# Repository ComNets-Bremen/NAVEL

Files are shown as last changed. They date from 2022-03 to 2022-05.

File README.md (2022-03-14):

# NAVEL - Logistics Innovation Center

Any country requires home grown solutions to solve problems faced by different stake holders of the society of those countries. One such area is in finding solutions to problems in ensuring the safety of food during transporting. The ideas and easy-to-use technology that is associated with the Internet of Things (IoT) enable developing cost-effective solutions to many such problems. NAVEL is the name given to a project funded by the German Aerospace Center (DLR) to build a Logistics Innovation Center in Cameroon. The aim of the project is to build a "Fab Lab" with computing hardware and the know-how, available to entrepreneurs to try out new ideas and tehnological solutions required in their businesses.

To demonstrate the possibilities of the Fab Lab, we have built simple IoT solutions for some selected use cases and the related problems. This repostory provides the details of these solutions in terms of the protypes developed and the training material required to build such protoypes.

We hope that this will inspire the users of the Fab Lab to find solutions to their problems.

The different sections of this repository is organized in the following manner.

- [Training Material](./training-material) - This sections provides a number of HOWTOs on using the technologies of the IoT to find solutions to problems.
- [Prototypes](./prototypes) - This section provides details of the different protoypes developed to show the possibilities of the Fab Lab.

Click on the link to browse the content of the section.

For inquiries about the material in this repository or comments, contacts us using navel@comnets.uni-bremen.de

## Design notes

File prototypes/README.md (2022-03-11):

# NAVEL - Prototypes

To demonstrate the possibilities of the FAB Lab, a prototypes are developed addressing specific yuse cases. The items listed below and their corresponding links provide details of each prototype developed.

- [Food Safety Prototype](./Food-Safety-Prototype)

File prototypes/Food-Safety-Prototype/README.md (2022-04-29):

# Food Safety Prototype

The Food Safety Prototype demonstrates how the resources available at the FAB Lab can be used to develop a solution for a specific use case. The use case relates to transporting meat or milk safely in Cameroon. This README provides the details of the scenario, the hardware used and the code of the prototype. The following locations have further details.

- [Design](./design/) - Contains the flow charts of the prograsm logic, pin assignments, etc.
- [Program code](./code/) - Contains the program code of the prototype

## Scenario

There are a number of different transportation means used by producers of meat and milk to deliver them to the sellers who will further process or sell directly to customers. During the transportation, the products are refrigerated but due to technical reasons, the refrigeration may fail. But, to know whether such a failure occured, there is not control mechanisms adopted.

The idea of this prototype is to build a self contained temperature monitoring device that is able to inform the sellers about the changes of the temperature during transport. The prototype will consit of a visual indicator to indicate whether temperature had exceeded a certain threshold during the transportation. Addition to this indications, the prototype also logs the temperature with time. For further analysis, the sellers can download this information to analyse the behaviour.

The picture below shows the protoype. It consist of the following components.

- Temperature sensor
- Button
- 3 LEDs (Red, Green and Yellow)

<p align="center">
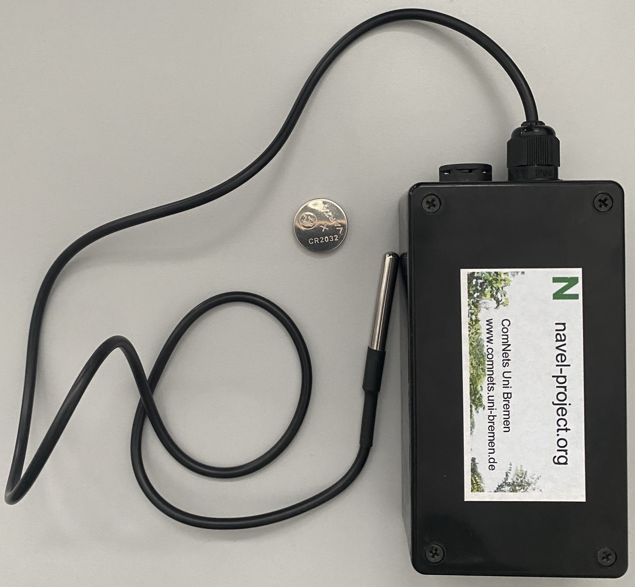
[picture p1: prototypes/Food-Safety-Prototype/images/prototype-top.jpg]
Prototype from top
    
</p>
<p align="center">
    <em>The protype from the top with its temperature sensor against the backdrop of a CR2032 coin battery</em>
</p>

<p align="center">
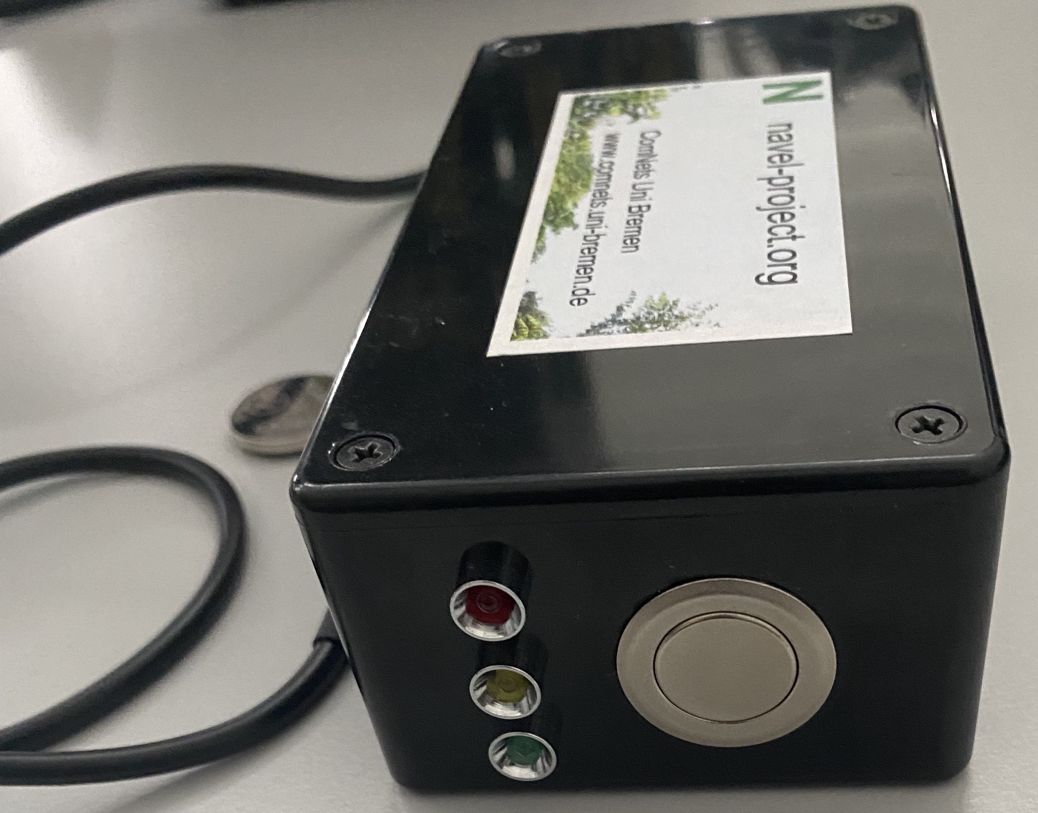
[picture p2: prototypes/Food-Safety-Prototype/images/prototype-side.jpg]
Prototype from side
    
</p>
<p align="center">
    <em>The protype from the side where the button and the 3 LEDs are visible</em>
</p>

The operation of the prototype is described in the following text.

- When the prototype boots up, the red and green LEDs will blink sequentially 3 times to indicate that it is ready for operation.
- When the button is pressed for a short time, between 3 and 7 seconds, the prototype will start logging the temperature. 
- The temperature will be logged every 10 seconds together with a green blink of the LED.
- When logging the temperature, if the average temperature from the last 8 readings exceeds a threshold (set to 7 degrees celcius), then the red LED will be lit permenently until a reset is done.
- If a long button press is performed, a press above 8 seconds, the a WLAN access point and a web server is brout up by the protype.
- The user can connect to this WLAN AP and use a web browser to browse and download data.
- A the same short press above, if done while the temperature is being logged, results in clearing the threshold exceed indicator (red LED) and starting a new round of temperature logging.

## Hardware

The prototype is based on the `Wemos D1 ESP8266` board placed together with other shields. The list of shields used are as follows.

- Wemos D1 ESP8266 shield
- SD card shield
- Battery shield
- Port explansion shield

The components attached to these sheilds are as follows.

- 3 LEDs (red green and yellow)
- DS18S20 temperature sensor connected over 1-wire interface
- Push button
- 3.7V 2600mAh rechargeable battery
- Cables connecting the pins and the components

The picture below shows the prototype opened up.

<p align="center">
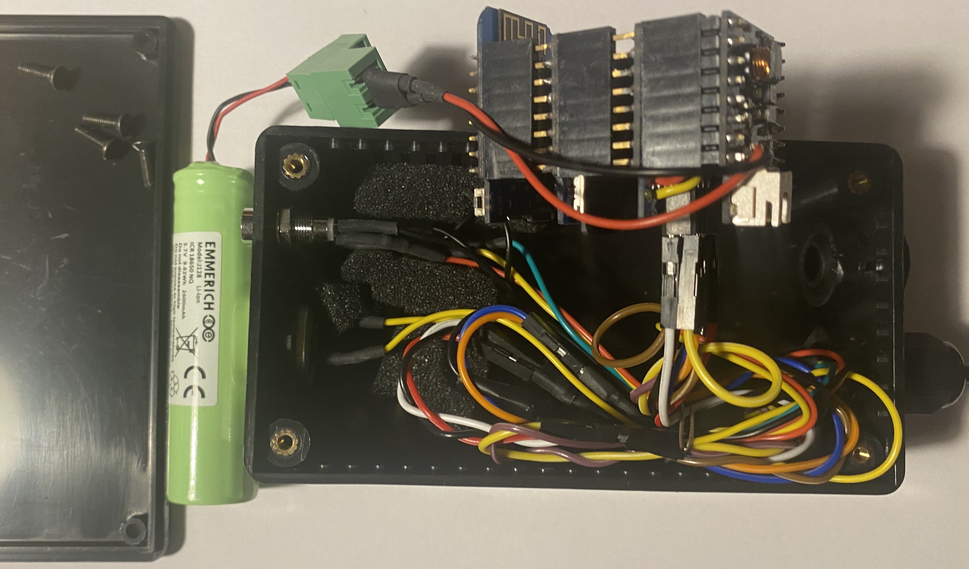
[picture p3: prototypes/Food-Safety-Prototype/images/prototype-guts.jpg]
Prototype guts
    
</p>
<p align="center">
    <em>The prototype open showing all components and connections</em>
</p>

The following table lists the pin assignments of the prototype.

| Pin on Board | Pin on ESP8266  | Details |
|---|---|---|
| TX | TXD | TXD (don't use) |
| RX | RXD | RXD (don't use) |
| A0 | A0 | Analog input, max 3.2V, not used |
| D0 | GPIO16 | Connected to RST |
| D1 | GPIO5 | Green LED |
| D2 | GPIO4 | Red LED |
| D3 | GPIO0 | Button -> GND (Pullup) |
| D4 | GPIO2 | IO, 10k Pull-up built-in LED, OneWire sensor Data  |
| D5 | GPIO14 | CLK SDcard |
| D6 | GPIO12 | MISO SDcard |
| D7 | GPIO13 | MOSI SDcard |
| D8 | GPIO15 | SS SDcard |
| G | GND | Ground |
| 5V | 5V | not available |
| 3V3 | 3.3V | 3.3V connection |
| RST | RST | Reset |

## Code

The code of the program consist of a number of parts (listed below) that are invoked to perform different activities. 

- Reading temperature sensor
- Averaging temperature values to check whether threshold exceeded
- Handling button presses (long press or short press) through an interrupt handler
- Setting up temperature logging
- Starting or stopping the WLAN access point and the web server
- Writing to SD card
- Setting up web server with the logged data
- Sleeping to save energy
- Serving web pages
- Forcing memory usage cleanup (garbage collection)

The following sections show and describe the code related to the above activities.

#### Reading temperature sensor

The sensor is connected over a [1-Wire](https://en.wikipedia.org/wiki/1-Wire) interface. This interface may be used by multiple sensors and therefore, it has to be initialized and a handle must be obtained for the temperature sensor to work with.

```Python
# Enable one wire temerature sensor
ow = onewire.OneWire(machine.Pin(2))
ow.scan()                # return a list of devices on the bus
ow.reset()               # reset the bus
ds = ds18x20.DS18X20(ow) # get handle
```

With the obtained handle, the function below retrives the value (i.e., the temperature) reported by the sensor.

```Python
# read temperature value from sensor
def read_sensors():
    temp = 0
    roms = ds.scan()
    ds.convert_temp()
    time.sleep_ms(750)
    res = {}
    for rom in roms:
        temp = ds.read_temp(rom)
        res[ubinascii.hexlify(rom)] = temp
    res["time"] = str(time.time())
    return res, temp
```
This part of the program code shows the actual call to the function to get the temperature and store it in a dictionary, so that it can be written to the log in the JSON format. 

```Python
# read temperature from sensor
data = {}
data["id"] = esp.flash_id()
data["data"], temp = read_sensors()
```

#### Averaging temperature and checking threshold

An array is maintained to collect the last 8 readings. These values are averaged  to check whether a threshold temperature value is exceeded. If exceeded, then the red LED must be lit until the next reset.

```Python

# add to list
average_list.append(temp)

# perform threshold check
if len(average_list) >= TEMP_AVG_FREQ:

    # compute average
    average = sum(average_list)/len(average_list)

    # init list
    average_list = []

    # check threshold to light red LED and log
    if average >= TEMP_EXCEED_LIMIT:
        led_red.value(1)
        data['msg'] = ('Threshold of ' + str(TEMP_EXCEED_LIMIT) + ' degrees was crossed')
```

#### Handling button presses

Button presses are handled using an interrupt handler. First the interrupt handler must be set.

```Python
# setup button handler (call function)
button.irq(handler=interrupt_handler, trigger=machine.Pin.IRQ_FALLING)
```

Once the interrupt handler is invoked, the button press duration must be calculated. A delay and a counter is used to figure out how long the button was pressed.

```Python
def interrupt_handler(x):
    global session, new_fileid

    # count button press duration
    x = 0
    while button.value() == 0:
        time.sleep(1)
        x += 1
```

#### Setup for temperature logging

If the press is short (between 3 and 7 seconds), then the green LED is blinked and temperature logging is initialized by creating a new log file.

```Python
# check if short press, then log temperature
if x >= 3 and x <= 7:

    # start temperature logging
    logstarted = True

    # init LEDs
    led_green.value(0)
    led_red.value(0)

    # blink green
    for i in range(6):
        led_green.value(not led_green.value())
        time.sleep(SLOW_BLINK_DURATION_SEC)

    # create new log file and log first temperature
    last_fileid += 1
    filename = '/sd/' + DATA_FILENAME + str(last_fileid)
    data = {}
    data['id'] = esp.flash_id()
    data['data'], temp = read_sensors()
    store_data(filename, data)
```

#### Setting up or brining down web server

If the press is long (beyond 8), then the red LED is blinked and actions related to brining up or taking down the WLAN access point and the we server are taken. This is indicated by the state variable `webstarted`.

The long press checking code is as follows.

```Python
# check if long press, then start web server
if x >= 8:

    # blink red
    for i in range(6):
        led_red.value(not led_red.value())
        time.sleep(SLOW_BLINK_DURATION_SEC)
    led_red.value(0)

    ...
```

Once the long presee is detected, then using the `webstarted` actions for starting or stopping web server is done. If the access point and web server are not up, the code below shows how it is brought up. 

```Python
 # start or stop WLAN AP and web server
 if not webstarted:

     # say web server and AP is active now
     webstarted = True

     # bring up WLAN AP
     ap = network.WLAN(network.AP_IF)
     ap.active(True)
     ap.config(password='navel2021')
     while ap.active() == False:
         pass

     # set up web server om port 80
     ssocket = socket.socket(socket.AF_INET, socket.SOCK_STREAM)
     saddr = socket.getaddrinfo('0.0.0.0', 80)[0][-1]
     ssocket.setsockopt(socket.SOL_SOCKET, socket.SO_REUSEADDR, 1) 
     ssocket.bind(saddr)
     ssocket.listen(5)
     ssocket.setblocking(False)

     # setup polling based connections
     poll = select.poll()
     poll.register(ssocket, select.POLLIN)
     time.sleep(2)
```
There are 3 distinct actions to bringing up the web server.

- start WLAN access point with default SSID and a password
- setup server socket to listen and bind to the port 80
- setup polling to detect incomming connections

If the web server is up when the long button press is done, then action is taken to bring down the access point and web server.

```Python
...

else:
    # say web server and AP is not active any more
    webstarted = False
    if DEBUG:
        print('stopping web server')

    # unregister polling
    poll.unregister(ssocket)

    # close socket
    ssocket.close()

    # shutdown WLAN AP
    ap = network.WLAN(network.AP_IF)
    ap.active(False)
```

In this code, the previously described distinct actions are undone in reverse order.

#### Writing to SD card

To use the DS card, a handle must be obtained and then it must be mounted as a file system.

```Python
# get handle to SD card for writing and mount as volume
sd = lib.sdcard.SDCard(machine.SPI(1), machine.Pin(15))
os.mount(sd, '/sd')

# log temperature value
def store_data(filename, data):
    with open(filename, "a") as outfile:
        outfile.write(json.dumps(data) + "\n")
        return outfile.tell() < DATA_MAX_FILE_SIZE
    return True

# initialize temperature logging file
def create_empty_file(filename):
    open(filename, 'a').close()
```

A function is used to write the temperature data to the log. This function additionally reports whether the file size determined by the user has exceeded or not. If the file size is exceeded, a new log file is created and the next temperature readinging will be written to the new file.

The functionality related to readig, writing, formating of an SD card is available in the `lib/sdcard.py` source file.

#### Sleeping to save energy

The usage scenario requires the prototype to run on a battery. Since it is required to be operated for long times (i.e., months), it must attempt at all times to save energy. A way to save energy is to send the prototype to sleep when suitable. A suitable time is between logging temperature. But, if the WLAN access point and web server is up, then sleep should not be activated as it must be ready to serve web pages.

```Python
# set for light sleep - only if logging started but no web server active
if logstarted and not webstarted:
    do_lightsleep = True
else:
    do_lightsleep = False

# check and do light sleep
if do_lightsleep:
    machine.lightsleep(SLEEP_INTERVAL_SEC * 1000)
```
In this prototype, the `machine.lightsleep()` function is used instead of a deep sleep to avoid resetting some of the hardware.

#### Serving web pages

Once the WLAN access point and web server are activated, the prototype must be ready to server web pages. The first activity is to see if there are pending connections.

```Python
# wait for incoming connections
status = poll.poll(SLEEP_INTERVAL_SEC * 1000)
```

This function will return for 2 reasons: either due to a new connection request or because of a timeout. If it is a new connection is requested, then a socket is created and the web request mest be processed.

```Python
# server pages when there are connections
if status:
    # setup connection to requester
    csocket, caddr = ssocket.accept()
    csocket.setblocking(True)

    # read user web request
    csocketfile = csocket.makefile('rwb', 0)
    
    # split request data to identify type
    selectfile = None
    while True:
        line = csocketfile.readline()
        utf8str = line.decode('utf-8')
        if utf8str.startswith('GET') and 'filename=' in utf8str:
            selectfile = utf8str.split(' ')[1].split('=')[1]
        if not line or line == b'\r\n':
            break

```
The requests may be for the following.

- First page (i.e., index page)
- Selected JSON file

The following program code shows the operation of serving pages for both requests.

```Python
# check request details decide what page to show
if not selectfile:
    # show index page with files
    # get first part of index page
    pagepart = ''
    with open('lib/index-part-1.html', 'r') as fp:
        pagepart = fp.read()
    csocket.send(pagepart)

    # get files part of index page
    for name in os.listdir('/sd'):
        pagepart = ('<option value=\"' + name + '\">' + name + '</option>\n')
        csocket.send(pagepart)

    # get last part of index page
    with open('lib/index-part-2.html', 'r') as fp:
        pagepart = fp.read()
        csocket.send(pagepart)
    
    # wait a little
    time.sleep(2)
else:
    # show contents of selected file
    csocket.sendall('HTTP/1.0 200 OK\r\nContent-type: application/json\r\n\r\n')
    csocket.sendall('[')

    # read file contents line by line to send
    with open('/sd/' + selectfile, 'r') as fp:
        isfirst = True
        for line in fp:
            if not isfirst:
                csocket.send(',')
            else:
                isfirst = False
            csocket.sendall(line)
    csocket.sendall(']')
```
Once the web page requested is served, the socket connection must be closed.

```Python
# end session
csocket.close()
```

#### Forcing memory usage cleanup

The ESP8266 is limited in its resource availability and therefore, releasing unused resources such as memory is critical to its proper function. This is done by actively calling gabage collection.

```Python
# release unwanted mem use
gc.collect()
```

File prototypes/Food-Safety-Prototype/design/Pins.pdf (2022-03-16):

Tabelle1

Pin | Function | ESP-8266 Pin | Shield | Comment
TX | TXD | TXD | | Do not use
RX | RXD | RXD | | Do not use
A0 | Analog input, max 3.2V | A0
D0 | IO | GPIO16 | | Wake pin, connect to RST for Deep Sleep
D1 | IO, SCL | GPIO5 | | I²C, future use
D2 | IO, SDA | GPIO4 | | I²C, future use
D3 | IO, 10k Pull-up | GPIO0 | Button
D4 | IO, 10k Pull-up, BUILTIN_LED | GPIO2 | LED, DHT
D5 | IO, SCK | GPIO14 | SD
D6 | IO, MISO | GPIO12 | SD
D7 | IO, MOSI | GPIO13 | SD
D8 | IO, 10k Pull-down, SS | GPIO15 | SD_CS | Check, differs between shields
G | Ground | GND
5V | 5V | -
3V3 | 3.3V | 3.3V
RST | Reset | RST

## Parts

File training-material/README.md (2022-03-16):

# NAVEL - Fab Lab Training Material

The Fab Lab is equipped with different computing hardware to combine and build IoT solutions. The information provided in this section is about using this hardware to build solutions. They are mostly written in the form of HOWTOs, but may contain other useful information on building solutions using the Fab Lab. The list below provides the current list of training material including the link to the material.

- [Introduction to the Internet of Things](./Introduction-to-the-Internet-of-Things/)
- [Developing Software for the ESP8266](./Developing-Software-for-the-ESP8266/)

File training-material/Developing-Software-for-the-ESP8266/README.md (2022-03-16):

# Developing Software for the ESP8266

There are different microcontrollers used in the Internet of Things (IoT) to build solutions. ESP8266 is one such microcontroller that comes with built in support for WLAN and the Internet Protocol (IP) stack. Different manufacturers package the ESP8266 on boards to make them complete systems, enabling users to provide different IoT solutions. There  are many ways of programming the ESP8266 to perform tasks and one of the most popular ways is using the MicroPython language.

In this HOWTO, we explain developing programs for the ESP8266 using the MicroPython language. We use the **Wemos D1 board** as the base system when explaing the development process. To load programs to the **Wemos D1 board**, it must be connected to a computer over USB. The picture below shows a **Wemos D1 board** placed on a Breadboard connected to a computer ready for loading programs.

<p align="center">
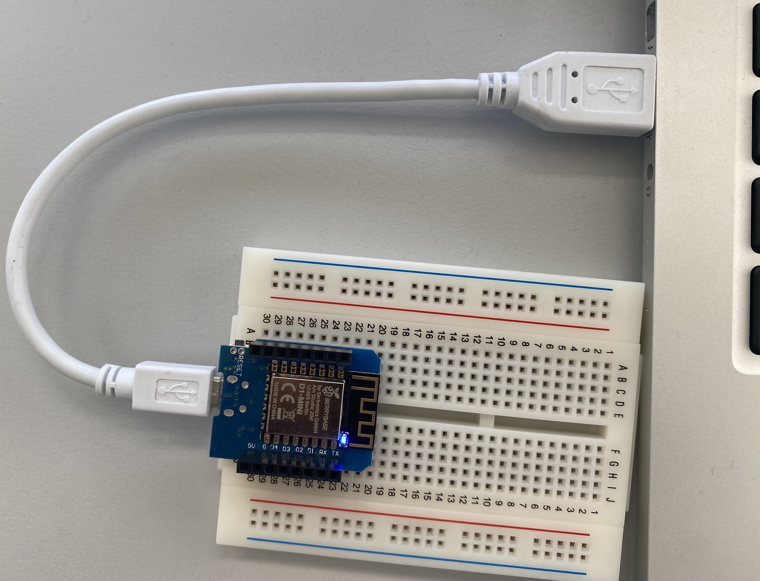
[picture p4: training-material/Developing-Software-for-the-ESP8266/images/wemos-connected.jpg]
Wemos D1 Board
    
</p>

This HOWTO consist of the following sections. Click on the link to go to the relevant section or read from the begining.

1. [Prerquisites](#prerequisites) - Describes what is required to setup a development environment for the ESP8266
2. [Setting Up the Development Environment](#setting-up-the-development-environment) - Details the setting up of the tools required to develop software for the ESP8266
3. [Flashing The Latest Firmware](#flashing-the-latest-firmware) - Describes how to flash the latest firmware on the ESP8266
4. [Developing and Loading a Simple Program](#developing-and-loading-a-simple-program) - Describes a how a simple program is programmed, including structure of the structure expected by the ESP8266 and how the developed program is loded
5. [Program to Read from a Temperature Sensor](#program-to-read-from-a-temperature-sensor) - Describes how a simple program that reads values from a temperature sensor connected to a ESP8266 is written and loaded
6. [Program to Write and Read an SD Card](#program-to-write-and-read-an-sd-card) - Describes how an SD card is used in an ESP8266

-----

## Prerequisites

Developing for the ESP8266 require the use of a number of other programs to write code and upload to the ESP8266. They have to be insatalled in your computer. They are as follows.

- Python Development Environment
- Python Package Manager
- Firmware Flashing Tool
- Node.js Development Environment
- Visual Studio Code Editor
- Pymakr Extension

A description of using these programs are given in the next sections.

-----

## Setting Up the Development Environment

#### 1. Python 3

Install Python 3 in your computer. There are many sources for installing Python. Please identify the best way to install Python for the specific operation system in your computer. Check the following link about inatalling Python 3.

  [https://www.python.org/downloads/](https://www.python.org/downloads/)

Some operating systems come pre-installed with Python. Run the following command in your computer to see if Python 3 is installed.

<p align="center">
Python Version
</p>

#### 2. Python Package Manager

Install the Python package manager `pip` in your computer. Check the following link to install `pip`

[https://packaging.python.org/en/latest/guides/installing-using-pip-and-virtual-environments/](https://packaging.python.org/en/latest/guides/installing-using-pip-and-virtual-environments/)

To check whether `pip` is installed, run the following command.

<p align="center">
    Python Version
</p>

#### 3. Firmware Flashing Tool

Install the firmware flashing tool `esptool` in your computer. Check the following link for installation details.

[https://docs.micropython.org/en/latest/esp8266/tutorial/intro.html](https://docs.micropython.org/en/latest/esp8266/tutorial/intro.html)

Once installed, check if it works as seen below.

<p align="center">
    Python Version
</p>

#### 4. Node.js

Install the Node.js development environment in your computer. Check the following link for installation details.

[https://nodejs.org/en/download/](https://nodejs.org/en/download/)

Once installed, check on the command line if installed.

<p align="center">
    Node.js Version
</p>

#### 5. Editor

The development and installation of programs is done using the Visual Studio Code editor of Microsoft. Check the following link for installation.

[https://code.visualstudio.com/download](https://code.visualstudio.com/download)

Once installed, check the applications area to see if `Visual Studio Code` is installed.

#### 6. Pymakr Extension

The Pymaker extension in Visual Studio Code enables the uploading of Micropython code to the ESP8266. To install Pymakr, run `Visual Studio Code` and click on the `Extensions` icon on the `Activity Bar` (left of the screen). The picture below shows Pymakr installed.

<p align="center">
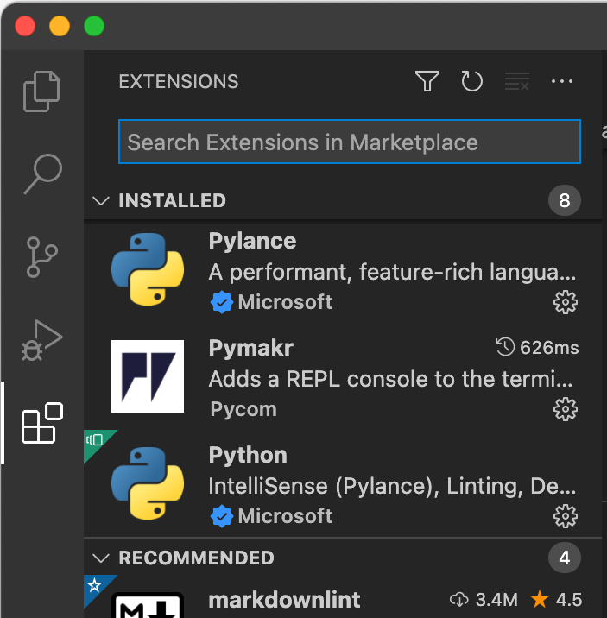
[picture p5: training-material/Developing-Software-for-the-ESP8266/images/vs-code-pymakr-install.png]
Pymakr Installed
    
</p>

#### 7. Connect ESP8266

Connect the ESP8266 board to the computer where your development envoronment (above) was installed. Since most ESP8266 boards use Micro USB ports, they usually usually use Micro USB to USB A cables to connect the board to the computer. The picture below shows a `Wemos` board connected to a computer.

<p align="center">
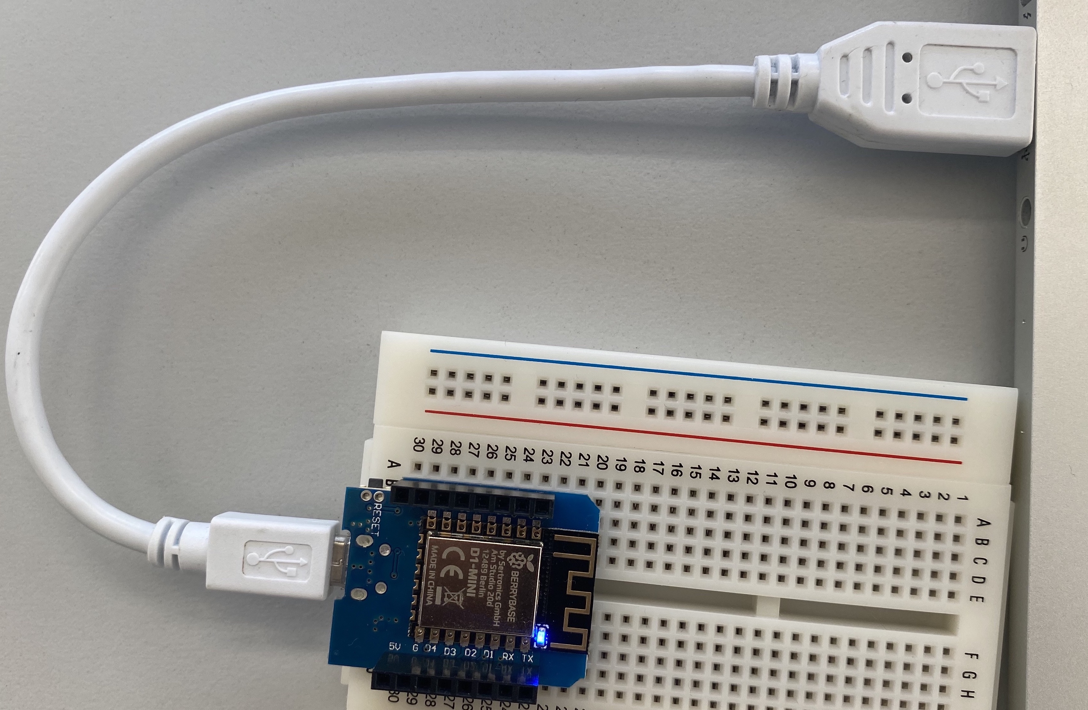
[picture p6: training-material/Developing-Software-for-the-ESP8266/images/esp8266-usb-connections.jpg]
    
</p>

When connected, the ESP8266 board will bring up a device entry in the computer. In Microsoft Windows, this is a `COM` port such as `COM3` which can be seen on the `Device Manager`. On MacOS or Linux, this will be a `/dev` entry such as `/dev/tty.usbserial-1410`. 

#### 8. Configure Pymakr

Once the Pymakr extension is installed and the ESP8266 board is connected, it's settings of Pymakr have to be adjusted. Sometimesa the port port name is detected automatically due to the default settings in the Pymakr. But, sometimes, the port name must be specified. The steps are as follows.

1. Click on the `All commands` button at the bottom of the Visual Studio Code editor (see picture below).

<p align="center">
    Pymakr All commands bar
</p>

2. Type `Pymakr > Global Settings` and select it (see picture below).

<p align="center">
    Pymakr Global Settings
</p>

3. Selecting `Global Settings` will open the `pymakr.json` file with all the settings of Pymakr. You are required to set the `address` and `auto_connect` variables to configure the port related information. In the example below, the port is set in a computer running MacOS. Details about the port name is given in [7. Connect ESP8266](#7-connect-esp8266).

```json
{
    ...
    "address": "/dev/tty.usbserial-1410",
    ...
    "auto_connect": false,
    ...
}
```

If the ESP8266 has been idenified by the Pymakr extension, then the following prompt should appear in the `TERMINAL` area of Visual Studio Code.

<p align="center">
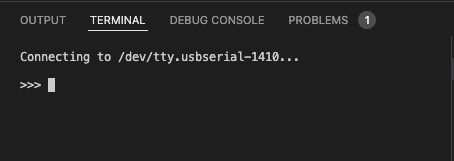
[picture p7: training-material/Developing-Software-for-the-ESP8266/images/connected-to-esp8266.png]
Pymakr Terminal after connected
    
</p>

The prompt you see is of a Micropython console. Type the following Micropython statement and check the output. The code will be executed in the ESP8266 microcontroller itself.

```Python
print('Hello World!!!')
```

-----

## Flashing The Latest Firmware

Once all the components of the development environment is setup in a computer as listed in [Setting Up the Development Environment](#setting-up-the-development-environment), you can use the `esptool` to flash the Micropython firmware. Listed below is the procedure.

#### 1. Download Micropython Firmware

There are different Micropython firmware versions for different micro-controllers. We use the `Espressif` versions of the firmware as the `Wemos` we use is bsased on ESP8266. Use the link below to find the right firmware.

[https://micropython.org/download/?port=esp8266](https://micropython.org/download/?port=esp8266)

For the `Wemos`, we use one of the firmwares shown in the picture below.

<p align="center">
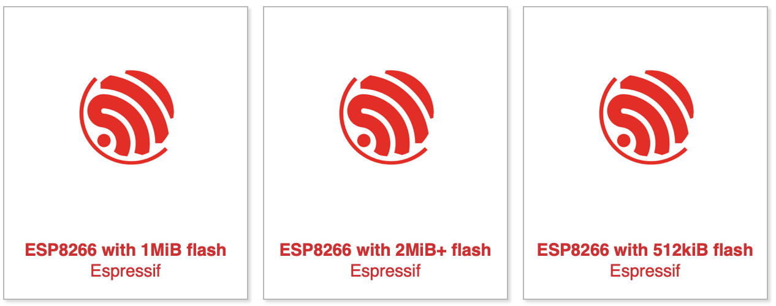
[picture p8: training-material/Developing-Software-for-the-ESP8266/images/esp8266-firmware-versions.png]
    
</p>

The firmware file is a `.bin` file which for example, may look like `esp8266-20210618-v1.16.bin`.

#### 2. Flash Firmware

The firmware is flashed using the downloaded `esptool` (described above). The command to run is als follows.

```
esptool.py --port /dev/tty.usbserial-1410 --baud 1000000 write_flash 
          --flash_size=4MB -fm dio 0 ./esp8266-20210618-v1.16.bin
```

When flashing the built-in blue LED of the ESP8266 board blinks to indicate activity.

-----

## Developing and Loading a Simple Program

The ESP8266 board comes with a built-in LED connected to the 2nd GPIO pin. In this section we write a simple program in Micropython to blink this LED 10 times.

The procedure for writing and loading the code to the ESP8266 is as follows.

#### 1. Create programming environment

Start Visual Studio Code and click on `Open` or `Open Folder` and once the dialog comes up, ceate a folder of with your preferred name. For this example, name it `blink`.

#### 2. File and folder structure

The Micropython firmware expects the following files and structure to be present in the program that is loaded. 

```
+-- boot.py
+-- main.py
+-- lib
    +-- comm.py
```

The `boot.py` is run first when the microcontroller boots and is used to include any one time configurations. The `main.py` is where the program of the user is written. In our simple example (below), we program the blinking of the built-in LED in the `main.py` file. The `lib` folder usually holds any additional Micropython files required in program.

#### 3. Write Program Code

The built-in LED os the ESP8266 board is connected to the GPIO pin number 2. We use the `Pin` class in the `machine` libraray of Micropython to control the built-in LED. The program below loops 10 times, each time lighting or switching off the LED. This makes the LED to appear as blinking. This program is coded in the `main.py` file. We leave the `boot.py` empty. 

```Python
# import required libraries
from machine import Pin
from time import sleep

# get reference to output pin 2
led = Pin(2, Pin.OUT)

# loop for 20 times
for i in range(20):
    # switch LED on/off
    led.value(not led.value())

    # wait for 1 second
    sleep(1)
```

The `led.value(not led.value())` statement switches LED on/off based on the current state - if it is currently on, then it is switched off, vise versa if it is currently off.  The `sleep(1)` requests the program to wait for a second after changing LED state.

#### 4. Code Errors

When writing code, there is always the possibility of making mistakes. Visal Studio Code shows whatever errors it can identify as errors. The picture below shows the program code with 2 errors (red arrows). 

<p align="center">
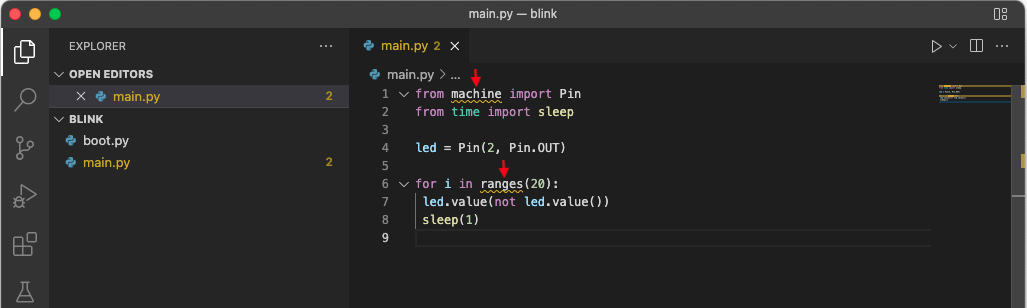
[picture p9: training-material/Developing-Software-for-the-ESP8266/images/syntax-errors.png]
    
</p>

If the mouse cursor is hovered above the error, Visual Studio Code will provide information about the error. The second error shown is a Micropython syntax error. The right keyword is `range`. In the first error, Visual Studio Code is complaining that the `machine` library is unknown. Visual Studio Code has only information about standard Python and its libraries, but is unaware of libraries of Micropython. Therefore, this error can be safely disregarded.

#### 5. Load program

Once the program is written, press the `Upload` button to load the program to the ESP8266. This action will not only load, but also start running the program. 

<p align="center">
    Pymakr upload button in bar
</p>

-----

## Program to Read from a Temperature Sensor

-----

## Program to Write and Read an SD Card

The ESP8266 board can be attached a Micro SD card to store aand read files. The picture below shows a Micro SD card sheild mounted on the ESP8266. 

<p align="center">
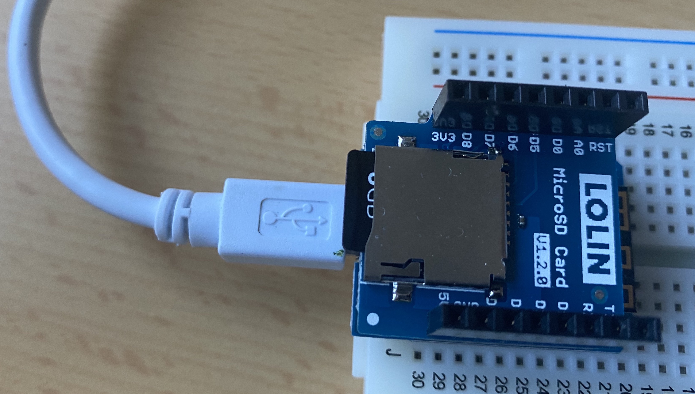
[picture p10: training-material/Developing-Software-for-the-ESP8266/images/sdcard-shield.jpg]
SD Card Shield
    
</p>

To use the SD card shield, a library must be used. This library has many functions related to reading, writing, formatting, etc. of the SD card. The procedure is as follows.

1. Use `Open Folder` or `Open` in Visual Studio Code to create folder, call it `sdcardcheck`

2. Downlod the source file (i.e., library) containing the SD card manipulation code from [SD Card Manipulation Library](res/sdcard.py)

3. The file structure should look like as follows.

```
+-- boot.py
+-- main.py
+-- lib
    +-- sdcard.py
```

4. Use the following program as the `main.py`

```Python
# import required libraries
import machine
import lib.sdcard
import os

# get reference to the SD card
sd = lib.sdcard.SDCard(machine.SPI(1), machine.Pin(15))

# mount SD card as a file system
os.mount(sd, '/sd')

# make a file name
filename = '/sd/testfile.txt'

# open file in append mode and write some text to a file
with open(filename, 'a') as fp:
    fp.write('Hello SD card \n')

# open file and read
with open(filename, 'r') as fp:
    print(fp.read())
```

5. Load the program as described previously

The `lib.sdcard.SDCard(machine.SPI(1), machine.Pin(15))` initializes and obtains a reference to the SD card to use for reading and writing to the SD card. The `os.mount(sd, '/sd')` command mounts that SD card as a volume at `/sd` folder. The rest of the program writes (`fp.write()`) a text string to a file and reads (`fp.read()`)what was written.

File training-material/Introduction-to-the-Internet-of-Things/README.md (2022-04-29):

# Introduction to the Internet of Things (IoT)

The Internet of Things (IoT) is defined by the Oxford Dictionary as `The connection of devices within everyday objects via the internet, enabling them to share data.` The embedded video below is an introduction to the IoT.

Introduction to the IoT (https://www.youtube.com/watch?v=zH1ipK-Rd8U "Introduction to the IoT")

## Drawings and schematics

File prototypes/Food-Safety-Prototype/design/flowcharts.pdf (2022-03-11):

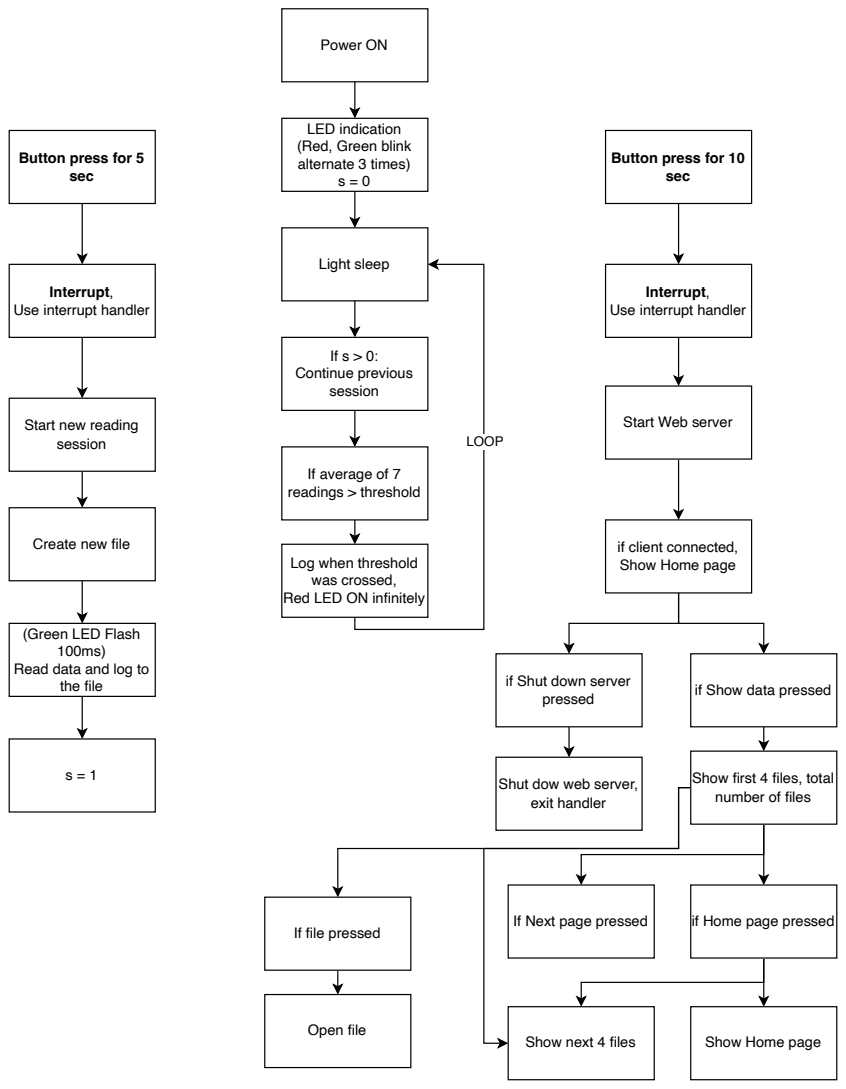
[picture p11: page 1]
Power ON; Light sleep; the file; If s > 0: Continue previous session; LOOP; sec; pressed; if Show data pressed; If Next page pressed; if Home page pressed; Show next 4 files; Show Home page; Open file

LED indication
(Red, Green blink
alternate 3 times)

Button press for 5

Button press for 10

Interrupt,
Use interrupt handler

Start new reading
session

Start Web server

If average of 7
readings > threshold

Create new file

if client connected,
Show Home page

Log when threshold
was crossed,
Red LED ON infinitely

(Green LED Flash

Read data and log to

if Shut down server

Show first 4 files, total
number of files

Shut dow web server,
exit handler

If file pressed

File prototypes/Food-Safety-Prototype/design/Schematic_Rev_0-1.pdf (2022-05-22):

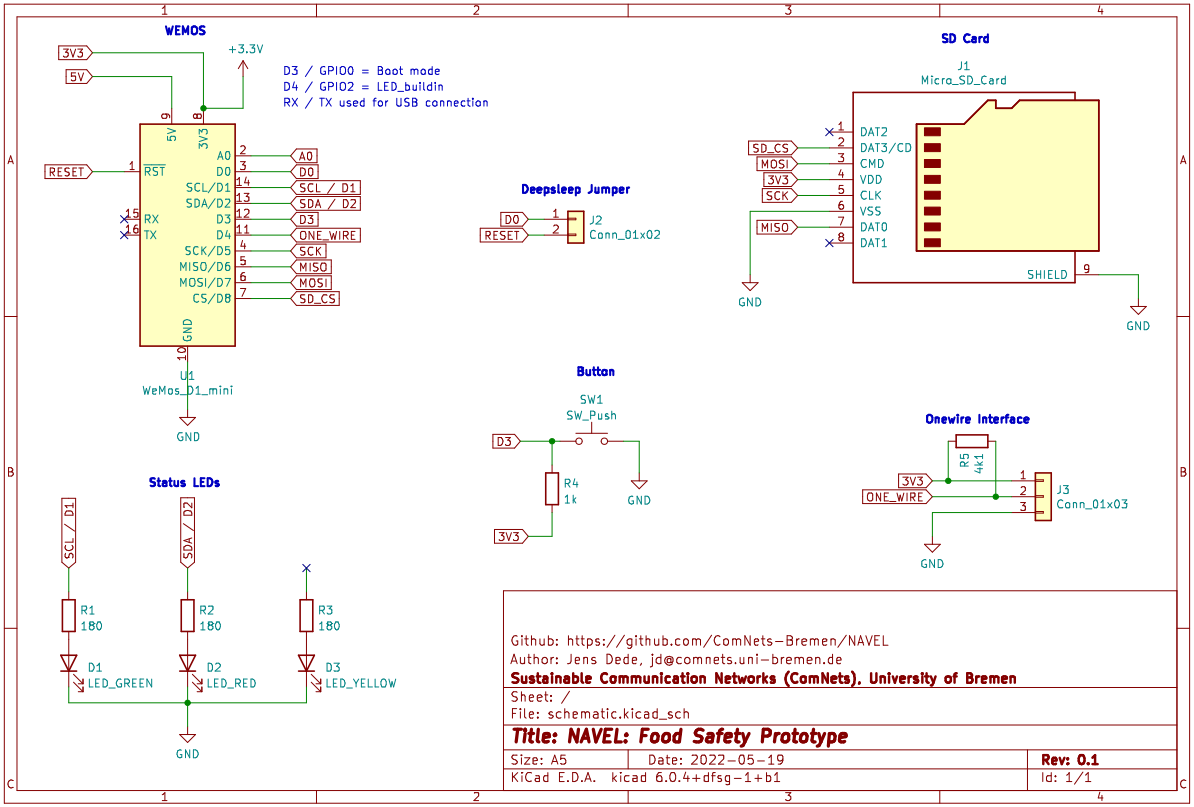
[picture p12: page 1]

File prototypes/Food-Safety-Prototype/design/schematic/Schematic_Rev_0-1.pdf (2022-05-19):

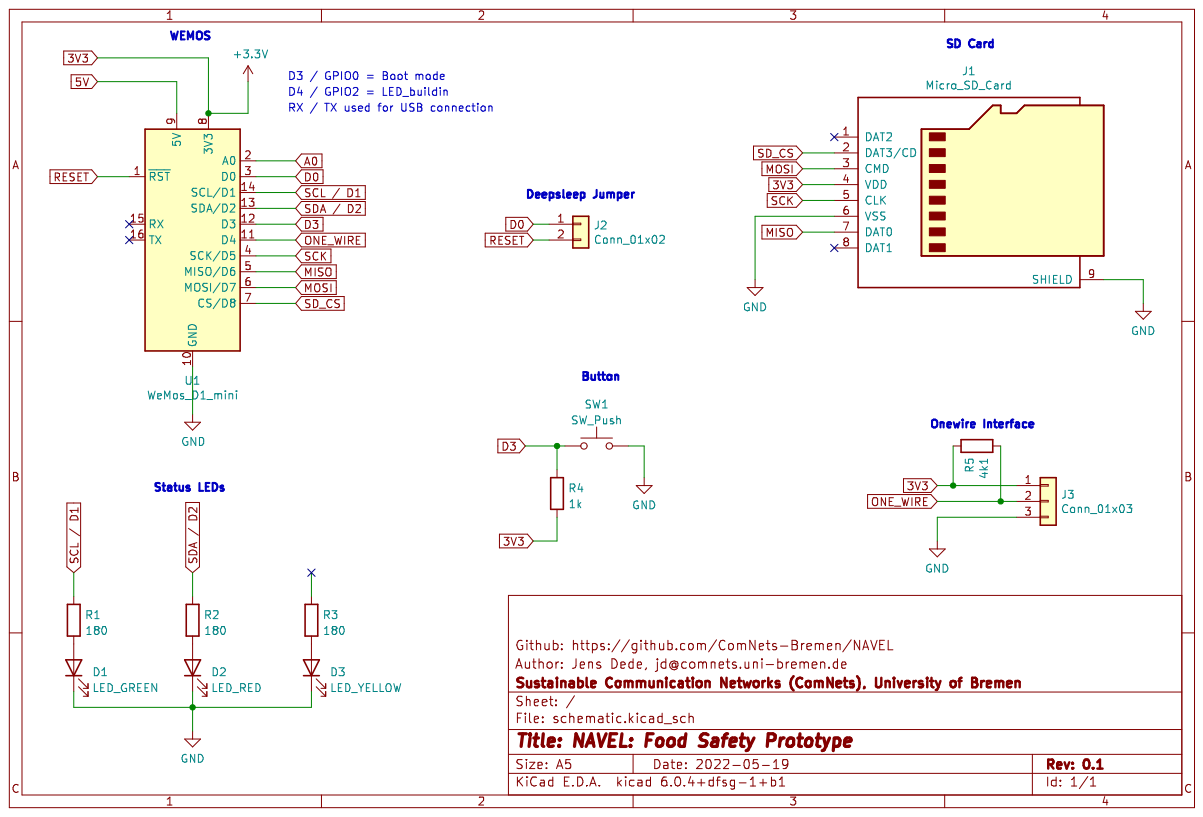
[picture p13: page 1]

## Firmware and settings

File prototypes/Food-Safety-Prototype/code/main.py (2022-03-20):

# Code of the Food Safety Prototype developed
# for the NAVEL project. This protype is based
# on the following hardware.
#
# - Wemos D1 ESP8266 board
# - DS18X20 temperature sensor
# - 3 LEDs (green, red, blue)
# - Button
# - Micro SD shield
# - battery shield and battery
# 
# The purpose of this hardware and program together
# is to sense the temperature when used in the
# 2 scenarios discussed for NAVEL and indicate when
# it exceeds a certain threshold.
#
# This code is based on the wemos/esp8266 data logger
# developed by Jens Dede <jd@comnets.uni-bremen.de>
#
# author: Eenesh Chavan <eenesh.chavan@uni-bremen.de>
# modified: Asanga Udugama <udugama@uni-bremen.de>
#

"""
PINs and usage

TX 	TXD 	TXD (don't use)
RX 	RXD 	RXD (don't use)
A0 	Analog input, max 3.2V 	A0 (not used)
D0 =  GPIO16 = (connected to RST)
D1 	= GPIO5 = Green LED
D2 = GPIO4  = Red Led
D3 = GPIO0   = Button -> GND (Pullup)
D4 	= GPIO2, IO, 10k Pull-up = BUILTIN_LED,= OneWire sensor Data 	
D5 = GPIO14  = CLK SDcard
D6 = GPIO12  = MISO SDcard
D7 = GPIO13  = MOSI SDcard
D8 = GIO15   = SS SDcard
G 	Ground 	GND
5V 	5V 	-
3V3 	3.3V 	3.3V
RST 	Reset 	RST
"""

# import all required libraries
import machine
import time
import os
import network
import esp
import onewire
import ds18x20
import lib.sdcard
import ujson as json
import ubinascii
import select
import socket
import gc
gc.collect()

# setup constants
DEBUG = True # keep True to check functioning of code
FAST_BLINK_DURATION_SEC = 0.1 # duration to light LED for fast blinking
SLOW_BLINK_DURATION_SEC = 0.5 # duration to light LED for slow blinking

# storage stuff
DATA_FILENAME = 'DATA_' # set file name
DATA_MAX_FILE_SIZE = 1*1000*1000 # 1M

# thresholds
SLEEP_INTERVAL_SEC = 10 # interval in secs for reading temperature
TEMP_AVG_FREQ = 8       # frequency of averaging temerature and logging
TEMP_EXCEED_LIMIT = 24  # temperate threshold (degrees celcius) to indicate red LED 

# log temperature value
def store_data(filename, data):
    with open(filename, 'a') as outfile:
        if DEBUG:
            print('Writing', filename)
        outfile.write(json.dumps(data) + '\n')
        if DEBUG:
            print('Filesize of', filename,':', outfile.tell())
        return outfile.tell() < DATA_MAX_FILE_SIZE
    return True

# initialize temperature logging file
def create_empty_file(filename):
    if DEBUG:
        print('Creating empty file', filename)
    open(filename, 'a').close()

# read temperature value from sensor
def read_sensors():
    temp = 0
    roms = ds.scan()
    ds.convert_temp()
    time.sleep_ms(750)
    res = {}
    for rom in roms:
        temp = ds.read_temp(rom)
        res[ubinascii.hexlify(rom)] = temp
    res['time'] = str(time.time())
    return res, temp

def read_stored_data(path='/sd/', remove = False):
    for f in os.listdir(path):
        if f.startswith(DATA_FILENAME):
            print('FILE', f)
            with open(path+f, 'r') as infile:
                for line in infile:
                    print(line, end='')
                print('')
            if remove:
                os.remove(path+f)



# Disable communication first to further reduce energy consumption
network.WLAN(network.STA_IF).active(False)
network.WLAN(network.AP_IF).active(False)

# pin connection
button = machine.Pin(0, machine.Pin.IN)
led_red = machine.Pin(4, machine.Pin.OUT)
led_green = machine.Pin(5, machine.Pin.OUT)
led = machine.Pin(2, machine.Pin.OUT) # built-in LED

# start indication
for i in range(10):
    led_red.value(not led_red.value())
    led_green.value(not led_red.value())
    time.sleep(SLOW_BLINK_DURATION_SEC)
led_red.value(0)
led_green.value(0)

# Enable one wire temerature sensor
ow = onewire.OneWire(machine.Pin(2))
ow.scan()                # return a list of devices on the bus
ow.reset()               # reset the bus
ds = ds18x20.DS18X20(ow) # get handle

# get handle to SD card for writing and mount as volume
sd = lib.sdcard.SDCard(machine.SPI(1), machine.Pin(15))
os.mount(sd, '/sd')

# number appended to log file name
last_fileid = 0

# find the last number of the last file name
for fn in os.listdir('/sd'):
    try:
        if DEBUG:
            print('Found file:', fn)
        last_fileid = max(last_fileid, int(fn.split('_')[1]))
    except:
        pass
if DEBUG:
    print('fileid', last_fileid)

# variable to keep track of current state
logstarted = False
webstarted = False

# socket details
ssocket = None
poll = None
saddr = None

def interrupt_handler(x):
    global logstarted, webstarted, last_fileid, ssocket, poll, saddr

    # count button press duration
    x = 0
    while button.value() == 0:
        time.sleep(1)
        x += 1
    
    # check if short press, then log temperature
    if x >= 3 and x <= 7:

        # start temperature logging
        logstarted = True

        # init LEDs
        led_green.value(0)
        led_red.value(0)

        # blink green
        for i in range(6):
            led_green.value(not led_green.value())
            time.sleep(SLOW_BLINK_DURATION_SEC)

        if DEBUG:
            print('starting temperature logging with new file')

        # create new log file and log first temperature
        last_fileid += 1
        filename = '/sd/' + DATA_FILENAME + str(last_fileid)
        if DEBUG:
            print('new file name', filename)
        data = {}
        data['id'] = esp.flash_id()
        data['data'], temp = read_sensors()
        if DEBUG:
            print(data)
        store_data(filename, data)

    # check if long press, then start web server
    if x >= 8:

        # blink red
        for i in range(6):
            led_red.value(not led_red.value())
            time.sleep(SLOW_BLINK_DURATION_SEC)
        led_red.value(0)

        # start or stop WLAN AP and web server
        if not webstarted:

            # say web server and AP is active now
            webstarted = True
            if DEBUG:
                print('starting web server')

            # bring up WLAN AP
            ap = network.WLAN(network.AP_IF)
            ap.active(True)
            ap.config(password='navel2021')
            while ap.active() == False:
                pass
            if DEBUG:
                print(ap.ifconfig())

            # set up web server om port 80
            ssocket = socket.socket(socket.AF_INET, socket.SOCK_STREAM)
            saddr = socket.getaddrinfo('0.0.0.0', 80)[0][-1]
            if DEBUG:
                print('server:', saddr)
            ssocket.setsockopt(socket.SOL_SOCKET, socket.SO_REUSEADDR, 1) 
            ssocket.bind(saddr)
            ssocket.listen(5)
            ssocket.setblocking(False)

            # setup polling based connections
            poll = select.poll()
            poll.register(ssocket, select.POLLIN)
            time.sleep(2)

        else:

            # say web server and AP is not active any more
            webstarted = False
            if DEBUG:
                print('stopping web server')

            # unregister polling
            poll.unregister(ssocket)

            # close socket
            ssocket.close()

            # shutdown WLAN AP
            ap = network.WLAN(network.AP_IF)
            ap.active(False)

# setup button handler (call function)
button.irq(handler=interrupt_handler, trigger=machine.Pin.IRQ_FALLING)

# ring buffer to keep temperature to average
average_list = []

# next temperature logging time
next_logtime = time.time() + SLEEP_INTERVAL_SEC

# start main loop of logging temperature
while True:
    
    # set for light sleep - only if logging started but no web server active
    if logstarted and not webstarted:
        do_lightsleep = True
    else:
        do_lightsleep = False

    # check and do light sleep
    if do_lightsleep:
        machine.lightsleep(SLEEP_INTERVAL_SEC * 1000)

    # log temperature if started (with short press)
    if logstarted and time.time() > next_logtime:

        if DEBUG:
            print('I woke up')

        # blink green
        led_green.value(1)
        time.sleep(FAST_BLINK_DURATION_SEC)
        led_green.value(0)

        # read temperature from sensor
        data = {}
        data['id'] = esp.flash_id()
        data['data'], temp = read_sensors()

        if DEBUG:
            print('after read_sensors')

        # add to list
        average_list.append(temp)

        if DEBUG:
            print('average array elements:', len(average_list), 'values:', average_list)

        # perform threshold check
        if len(average_list) >= TEMP_AVG_FREQ:

            # compute average
            average = sum(average_list)/len(average_list)
            if DEBUG:
                print('average:', average)

            # init list
            average_list = []

            # check threshold to light red LED and log
            if average >= TEMP_EXCEED_LIMIT:
                led_red.value(1)
                data['msg'] = ('Threshold of ' + str(TEMP_EXCEED_LIMIT) + ' degrees was crossed')

            # release garbage
            gc.collect()

        if DEBUG:
            print(data)

        # log temperature data and check file size exceeded
        filename = '/sd/' + DATA_FILENAME + str(last_fileid)
        if not store_data(filename, data):

            # create new file for next log if size exceeded
            last_fileid += 1
            filename = '/sd/' + DATA_FILENAME + str(last_fileid)
            create_empty_file(filename)

        # setup for next temperature logging time
        next_logtime = time.time() + SLEEP_INTERVAL_SEC

    # serve web pages if web server up
    if webstarted:

        # wait for incoming connections
        status = poll.poll(SLEEP_INTERVAL_SEC * 1000)

        # server pages when there are connections
        if status:
            if DEBUG:
                print('connection request on local address', saddr)

            # setup connection to requester
            csocket, caddr = ssocket.accept()
            csocket.setblocking(True)

            # read user web request
            csocketfile = csocket.makefile('rwb', 0)
            if DEBUG:
                print('received:', 'from', caddr, '\n')
            
            # split request data to identify type
            selectfile = None
            while True:
                line = csocketfile.readline()
                if DEBUG:
                    print(line)
                utf8str = line.decode('utf-8')
                if utf8str.startswith('GET') and 'filename=' in utf8str:
                    selectfile = utf8str.split(' ')[1].split('=')[1]
                if not line or line == b'\r\n':
                    break
            
            # check request details decide what page to show
            if not selectfile:
                # show index page with files
                if DEBUG:
                    print('sending index page to', caddr, '\n')

                # get first part of index page
                pagepart = ''
                with open('lib/index-part-1.html', 'r') as fp:
                    pagepart = fp.read()
                csocket.send(pagepart)

                # get files part of index page
                for name in os.listdir('/sd'):
                    pagepart = ('<option value=\"' + name + '\">' + name + '</option>\n')
                    csocket.send(pagepart)

                # get last part of index page
                with open('lib/index-part-2.html', 'r') as fp:
                    pagepart = fp.read()
                    csocket.send(pagepart)
                
                # wait a little
                time.sleep(2)
            else:
                # show contents of selected file
                csocket.sendall('HTTP/1.0 200 OK\r\nContent-type: application/json\r\n\r\n')
                csocket.sendall('[')

                # read file contents line by line to send
                with open('/sd/' + selectfile, 'r') as fp:
                    isfirst = True
                    for line in fp:
                        if not isfirst:
                            csocket.send(',')
                        else:
                            isfirst = False
                        csocket.sendall(line)
                csocket.sendall(']')

            # end session
            csocket.close()

            # release unwanted mem use
            gc.collect()

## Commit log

2022-03-11 fixes to READMEs and other files
    [main.py]
2022-03-16 Structured prototype code
2022-03-16 prototype description update
2022-03-16 update to prototype description
2022-03-17 update to prototype details
2022-03-20 more updates to prototype description
2022-05-19 1st draft of schematic, to be checked.
    [schematic.kicad_pcb, schematic.kicad_sch, schematic.sch]
